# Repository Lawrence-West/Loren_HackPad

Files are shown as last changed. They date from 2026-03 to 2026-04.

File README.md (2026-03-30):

# Loren_HackPad
Hi LorenHackPad is 3x3 macropad with a rotary encoder, an OLED display and two status LEDs.

I First started by building the schematics

then I proceded by creating the routing for the pcb

after that I realized the case

as you can see I went for a bit of particular one, since I wanted the components to be visible but also the numpad to be as minimalistic as possible and to reduce to the mininum the weight and the use of material.
and after a bit of code that you can find in the firmware folder this should be the final results
my hackpad feature a knob with wich you can regulate the volume and an oled display to show live time, date and weather. the switches are programmable and I personally chose tto assign them tto some shortcuts such as steam or spotify. 

BOA:

-1 Seed xiao rp2040

-9 through-hole 1N4148 Diodes

-1  EC11 Rotary encoder

-1 0.91 inch OLED display

-2 SK6812 MINI-E LEDs

-4 M3x12mm screws

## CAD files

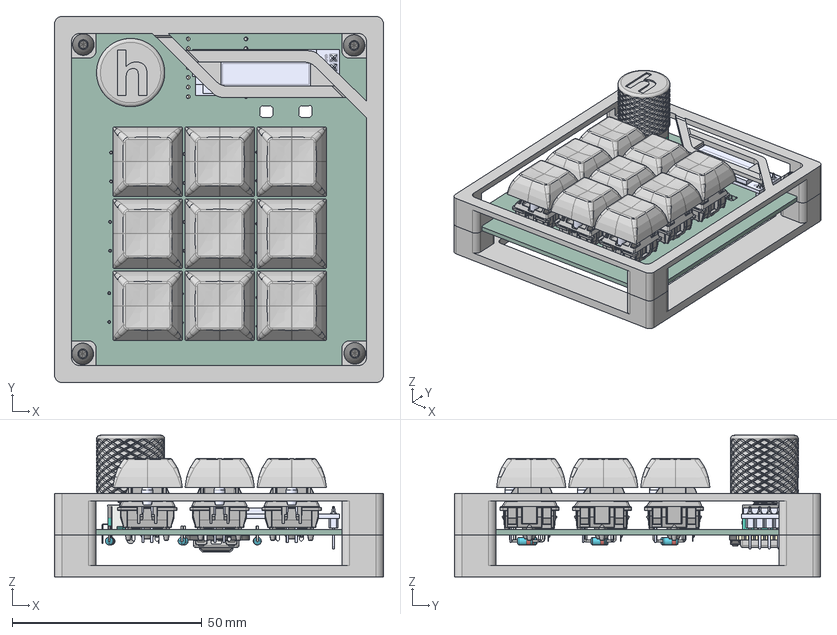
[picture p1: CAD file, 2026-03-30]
Loren_Hackpad/CAD/LorenHackpad.step
86.8 x 96.6 x 37.3 mm
Ðý×ª±àÂëÆ÷
MX Öá °´¼ü¡ä_¨¹ ___¡§1 x 9
MX Öá ÖáÌå¨¢¨¬ _¡§¡é¡§__ x 9
MXÖá ÎÞÃ±LEDLEDLED x 9
MXÖá ÖáÌå µ×²¿ ¦Ì¡ Á2__Ä¬ÈÏ_¨¢2____¨¨_ x 9
Õë½Å___Ä¬ÈÏ__¨¨ _ x 9
type-c v2
smd_button v3
DOUT
DIN
VSS
VDD
smd_button v3(Mirror)
0.91in OLED
D_DO-35_SOD27_P7.62mm_Horizontal x 9
LorenHackpad_PCB
Keycap_adjusted x 9
upper_part
lower_part
knob
ISO 7380-1 - M3 x 12 Steel 4.6 Black x 4

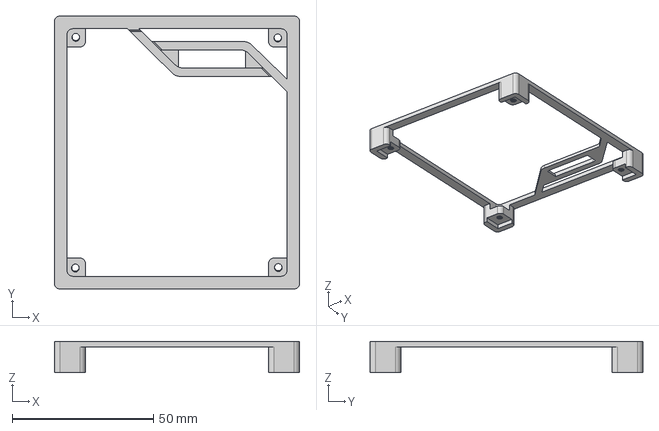
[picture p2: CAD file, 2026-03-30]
Loren_Hackpad/Production/CaseProduction/Upper_Part.step
86.8 x 96.6 x 11.0 mm

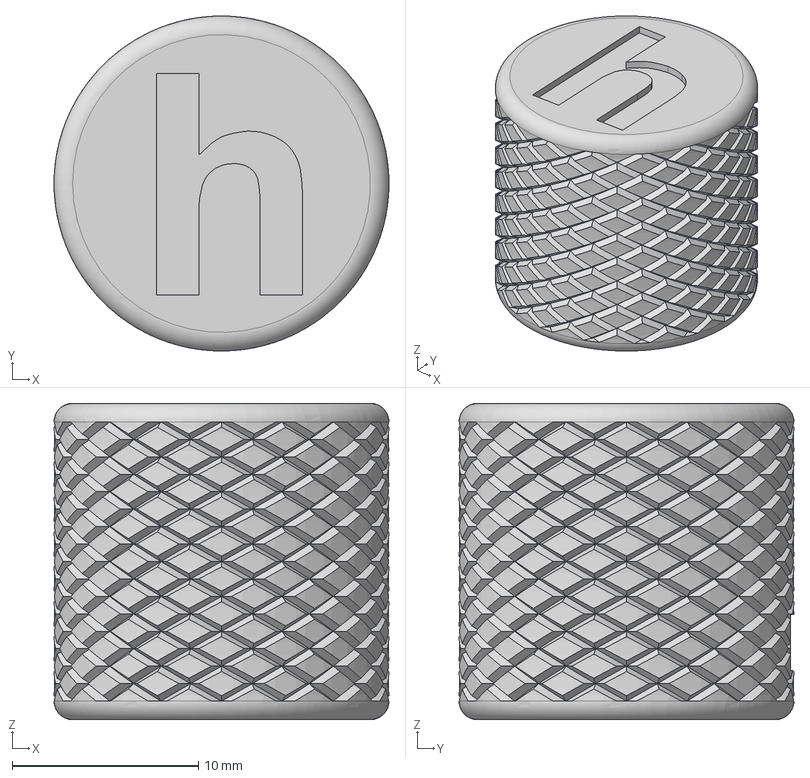
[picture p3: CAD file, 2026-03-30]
Loren_Hackpad/Production/CaseProduction/knob.step
18.0 x 18.0 x 17.0 mm

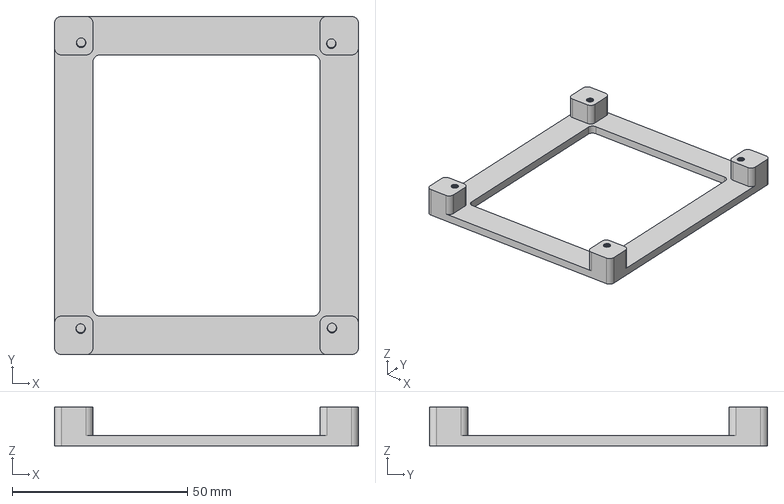
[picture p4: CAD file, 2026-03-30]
Loren_Hackpad/Production/CaseProduction/Lower_Part.step
86.8 x 96.6 x 11.0 mm

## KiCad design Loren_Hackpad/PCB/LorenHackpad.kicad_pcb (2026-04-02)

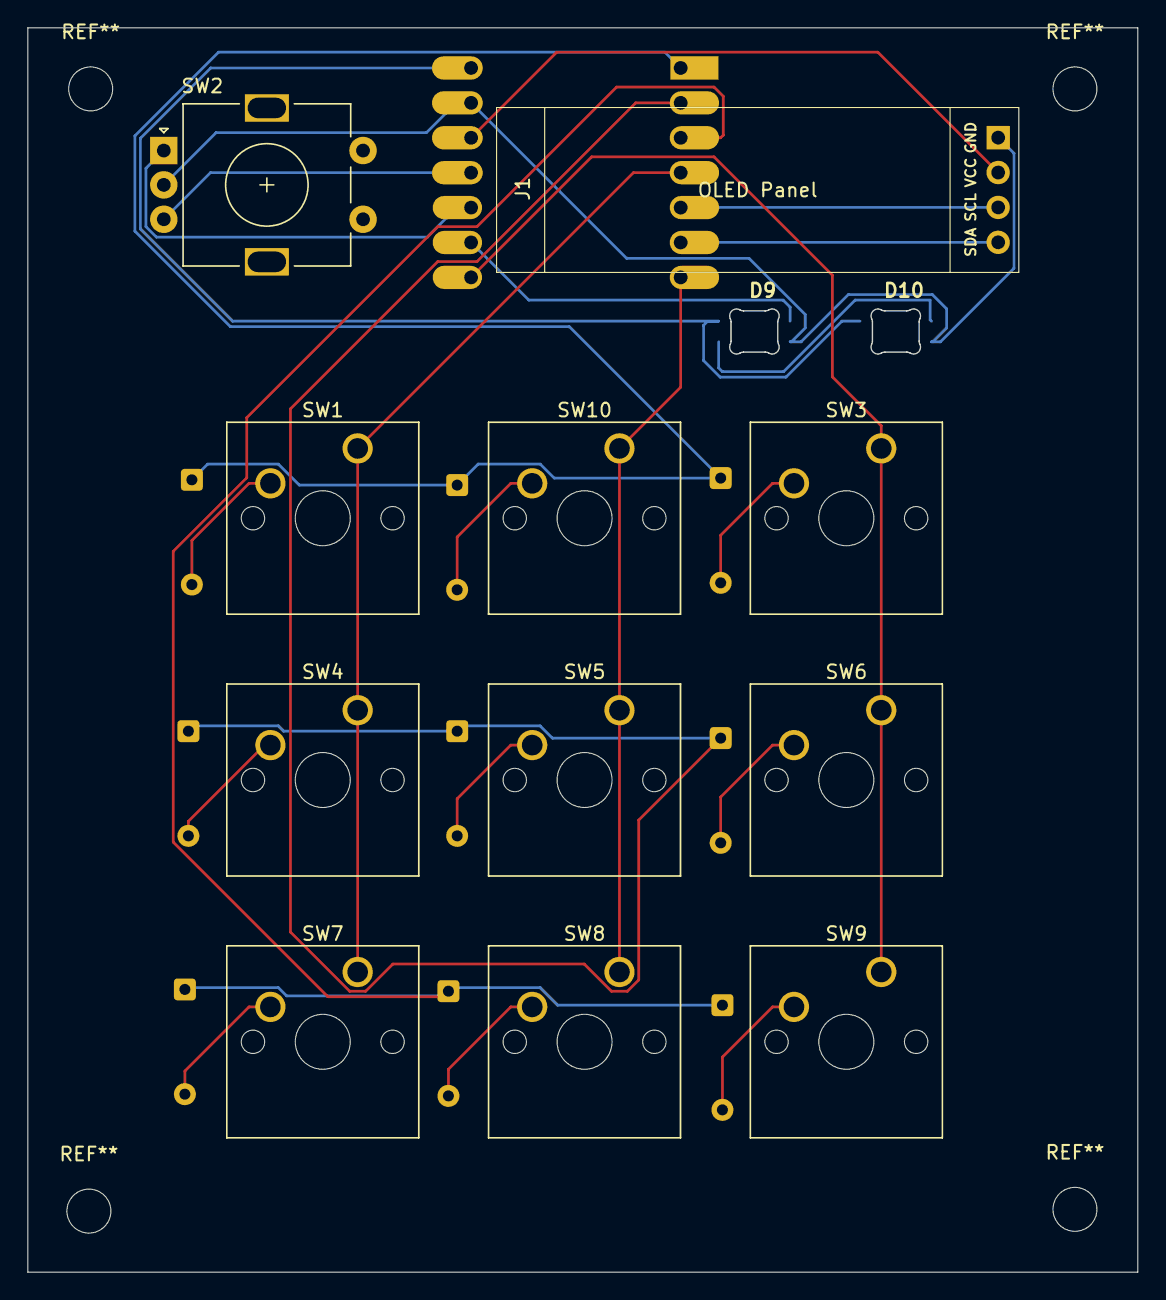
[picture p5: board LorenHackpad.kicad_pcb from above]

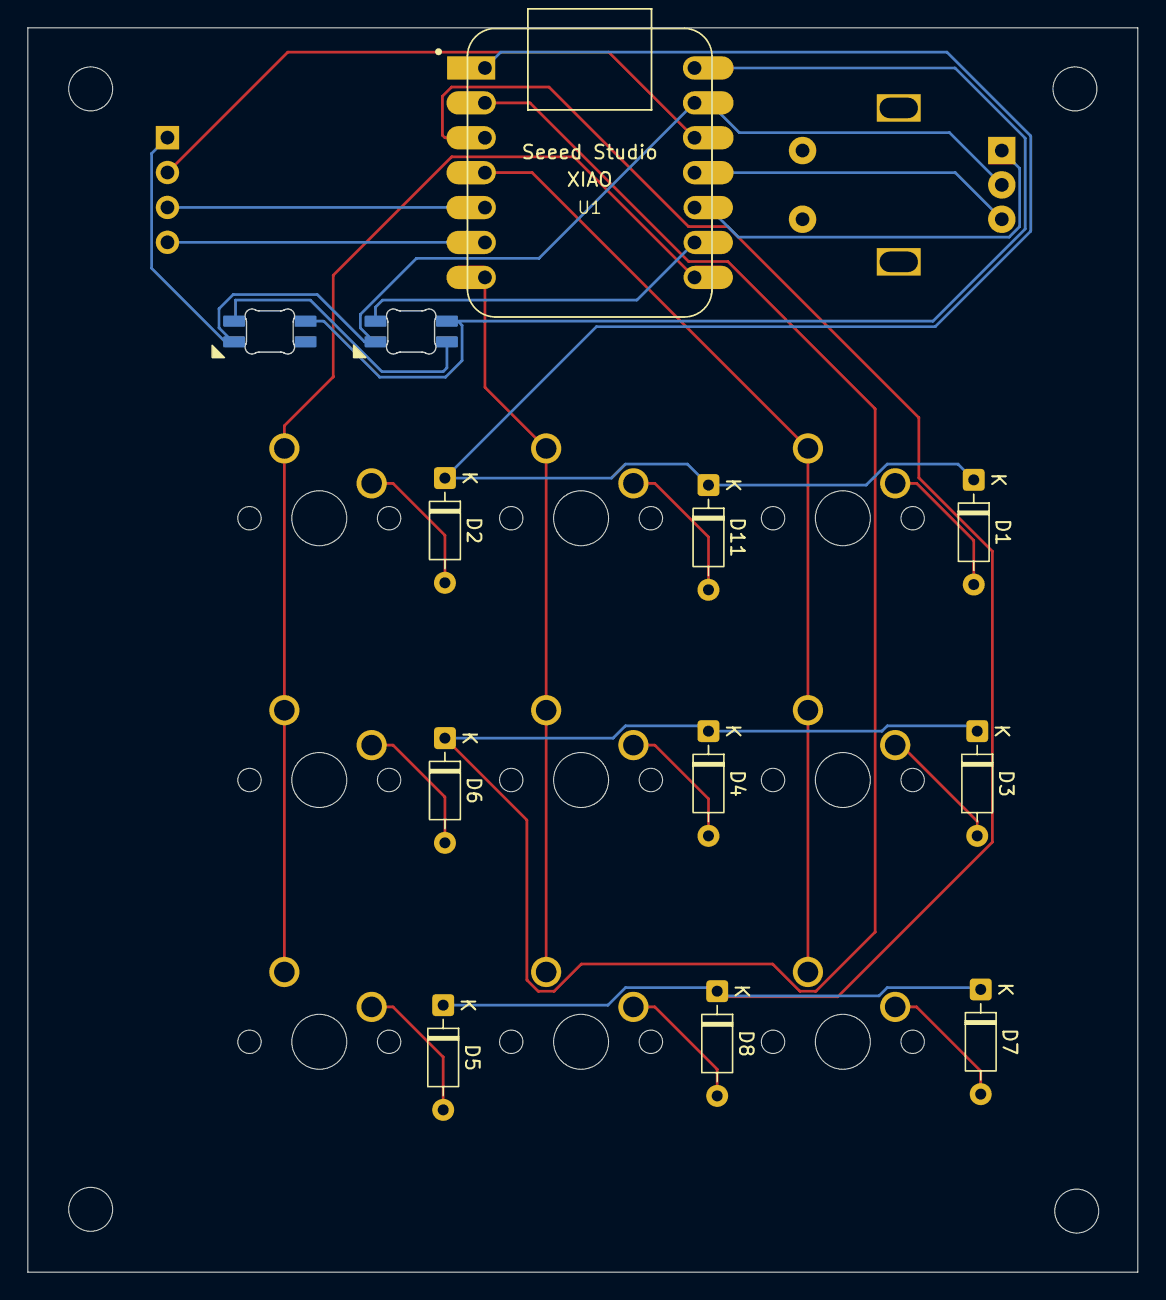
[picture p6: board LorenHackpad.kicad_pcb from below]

Board: 2 copper layers, 80.8 x 90.6 mm, 23 parts (10 on the bottom side), 24 nets.

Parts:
D1, D2, D3, D4, D5, D6, D7, D8, D11: 1N4148; D_DO-35_SOD27_P7.62mm_Horizontal
D9, D10: SK6812MINI-E; SK6812MINI-E_fixed
J1: OLED_display; SSD1306-0.91-OLED-4pin-128x32
SW1, SW3, SW4, SW5, SW6, SW7, SW8, SW9, SW10: SW_Push; SW_Cherry_MX_1.00u_PCB
SW2: RotaryEncoder_Switch; RotaryEncoder_Alps_EC11E-Switch_Vertical_H20mm
U1: XIAO-RP2040-DIP; XIAO-Generic-Hybrid-14P-2.54-21X17.8MM

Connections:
+3V3: J1.2, U1.12 (3V3)
+5V: D9.1 (VDD), D10.1 (VDD), U1.14 (VBUS)
COL0: SW1.1, SW4.1, SW7.1, U1.4 (GPIO29/ADC3/A3)
COL1: SW5.1, SW8.1, SW10.1, U1.7 (GPIO0/TX)
COL2: SW3.1, SW6.1, SW9.1, U1.8 (GPIO1/RX)
EC11A: SW2.A, U1.10 (GPIO4/MISO)
EC11B: SW2.B, U1.11 (GPIO3/MOSI)
GND: D9.3 (VSS), D10.3 (VSS), J1.1, SW2.C, U1.13 (GND)
unnamed: D1.2 (A), SW1.2
unnamed: D2.2 (A), SW3.2
unnamed: D3.2 (A), SW4.2
unnamed: D4.2 (A), SW5.2
unnamed: D5.2 (A), SW9.2
unnamed: D6.2 (A), SW6.2
unnamed: D7.2 (A), SW7.2
unnamed: D8.2 (A), SW8.2
unnamed: D9.2 (DOUT), D10.4 (DIN)
unnamed: D11.2 (A), SW10.2
ROW0: D1.1 (K), D2.1 (K), D11.1 (K), U1.1 (GPIO26/ADC0/A0)
ROW1: D3.1 (K), D4.1 (K), D6.1 (K), U1.2 (GPIO27/ADC1/A1)
ROW2: D5.1 (K), D7.1 (K), D8.1 (K), U1.3 (GPIO28/ADC2/A2)
SCL: J1.4, U1.6 (GPIO7/SCL)
SDA: J1.3, U1.5 (GPIO6/SDA)
SK6812MINI-E: D9.4 (DIN), U1.9 (GPIO2/SCK)

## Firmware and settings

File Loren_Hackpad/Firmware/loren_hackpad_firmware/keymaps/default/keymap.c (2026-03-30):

#include QMK_KEYBOARD_H
#include "raw_hid.h"
#include <string.h>

static char oled_time[9] = "00:00:00";
static char oled_date[11] = "00/00/0000";
static uint8_t oled_weather = 0;

#ifdef OLED_ENABLE
static const char* weather_icon(uint8_t code) {
    switch (code) {
        case 0: return " [SOLE]   ";
        case 1: return " [NUVOLA] ";
        case 2: return " [PIOGGIA]";
        case 3: return " [NEVE]   ";
        case 4: return " [TEMPORA]";
        case 5: return " [NEBBIA] ";
        default: return " [---]    ";
    }
}
#endif
void raw_hid_receive(uint8_t *data, uint8_t length) {
    if (data[0] == 0x01) {
        memcpy(oled_time, &data[1], 8);
        oled_time[8] = '\0';
        memcpy(oled_date, &data[9], 10);
        oled_date[10] = '\0';
        oled_weather = data[19];
    }
}

enum custom_keycodes {
    OPEN_SPOTIFY = SAFE_RANGE,
    OPEN_CHROME,
    OPEN_STEAM,
};

const uint16_t PROGMEM keymaps[][MATRIX_ROWS][MATRIX_COLS] = {
    [0] = LAYOUT(
        KC_MPRV,       KC_MPLY,       KC_MNXT,
        KC_BRIU,       KC_BRID,       LGUI(LSFT(KC_S)),
        OPEN_SPOTIFY,  OPEN_CHROME,   OPEN_STEAM
    ),
};

#ifdef ENCODER_MAP_ENABLE
const uint16_t PROGMEM encoder_map[][NUM_ENCODERS][NUM_DIRECTIONS] = {
    [0] = { ENCODER_CCW_CW(KC_VOLD, KC_VOLU) },
};
#endif

bool process_record_user(uint16_t keycode, keyrecord_t *record) {
    if (record->event.pressed) {
        switch (keycode) {
            case OPEN_SPOTIFY:
                SEND_STRING(SS_LGUI("r"));
                wait_ms(200);
                SEND_STRING("spotify\n");
                return false;
            case OPEN_CHROME:
                SEND_STRING(SS_LGUI("r"));
                wait_ms(200);
                SEND_STRING("chrome\n");
                return false;
            case OPEN_STEAM:
                SEND_STRING(SS_LGUI("r"));
                wait_ms(200);
                SEND_STRING("steam\n");
                return false;
        }
    }
    return true;
}

#ifdef OLED_ENABLE
oled_rotation_t oled_init_user(oled_rotation_t rotation) {
    return OLED_ROTATION_0;
}

bool oled_task_user(void) {
    oled_write_P(PSTR("Ora:  "), false);
    oled_write_ln(oled_time, false);
    oled_write_P(PSTR("Data: "), false);
    oled_write_ln(oled_date, false);
    oled_write_ln(weather_icon(oled_weather), false);
    oled_write_ln_P(PSTR("Lorenzo's Hackpad"), false);
    return false;
}
#endif

#ifdef RGBLIGHT_ENABLE
void keyboard_post_init_user(void) {
    rgblight_setrgb(120, 120, 120);
}
#endif
